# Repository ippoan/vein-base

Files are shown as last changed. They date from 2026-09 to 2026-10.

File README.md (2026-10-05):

# vein-base

M5Stack **Atom VoiceS3R** の下に積むベースです。**指静脈モジュール Waveshare Finger Vein Scanner Module (A)** を UART でつなぐための中継基板と、上蓋なしの 1 部品のケース(カップ)で構成しています。

ケース(`vein_base_v<版>_cup`)は床・ネジのボス・基板を支えるレールに、基板を囲む壁を立ち上げた形です。M5 の Atomic 系ベースと同じく、VoiceS3R は Ext.Pin のピンに刺して上に載せるだけで、外側は囲みません。壁の上端は VoiceS3R の底面から 0.25 mm 下で止め、ピンヘッダーのすき間を隠します(外形 24.4 × 33.1 × 9.25 mm、壁は全方向 1.4 mm 以上)。基板に合わせて USB-C と反対側(+y)へ伸びていて、その面に J3 のケーブル用の上へ開いた溝があります。

**3D プレビュー:** https://ippoan.github.io/vein-base/(回転・分解表示・部品の表示切替ができます)

3D プレビュー(GitHub Pages、main の CI が更新。各ページから型紙・加工図もダウンロードできます):

| 案 | ページ |
|---|---|
| vein-base(単体) | https://ippoan.github.io/vein-base/ |
| Vein Station(印刷筐体) | https://ippoan.github.io/vein-base/station/ |
| Vein Station SE(CoreS3 SE) | https://ippoan.github.io/vein-base/station-se/ |
| Vein Station PF(タカチ PF13-4-9) | https://ippoan.github.io/vein-base/station-pf/ |
| Vein Station SW(タカチ SW-85B) | https://ippoan.github.io/vein-base/station-sw/ |
| Vein Station SW75(タカチ SW-75B) | https://ippoan.github.io/vein-base/station-sw75/ |
| Vein Station SW130(タカチ SW-130B) | https://ippoan.github.io/vein-base/station-sw130/ |
| Vein Station 3D 印刷の試作 A(一列・薄型) | https://ippoan.github.io/vein-base/station-print-a/ |
| Vein Station 3D 印刷の試作 B(2 列・短い) | https://ippoan.github.io/vein-base/station-print-b/ |
| 指静脈 Unit(CS75N-B) | https://ippoan.github.io/vein-base/vein-unit-cs/ |
| 指静脈 Unit(SIC5-9-2B) | https://ippoan.github.io/vein-base/vein-unit-sic/ |

## 構成

```
VoiceS3R(Ext.Pin メス)
  └ 中継基板 20.0×29.9 mm(J1 1x5 / J2 1x4 オスピン、J3 MX1.25 4P 横型。全部品が表面 = VoiceS3R 側。J3 は VoiceS3R の外、USB-C の反対側の端)
  └ カップ 24.4×33.1(基板の下と周りだけ。VoiceS3R は囲まない。M2×12 ネジ 1 本で全体を VoiceS3R に共締め)
```

組み立て: VoiceS3R に基板を挿す → 指静脈のケーブルを J3 に挿す(挿さり具合を目で確かめられる)→ カップを下から差し込む(ケーブルは USB-C と反対側(+y)の壁の、上へ開いた溝を通る)→ 底から M2 ネジで締める。

- **挿し口:** 指静脈ケーブル(J3)は、VoiceS3R の USB-C / PORT.A(NFC 用)と**反対の面**に出ます。J3 は高さ 3.4 mm で VoiceS3R の下(すき間 2.54 mm)に入らないため、基板を VoiceS3R の外まで伸ばして載せています。
- **ケーブル:** 指静脈モジュール付属の 9P→4P ケーブルを使います。9P 側の端子を 1→5、2→6 の位置へ差し替えてください。
  付属ケーブルが使えない(端子の差し替えができない・長さが合わない)場合は、最悪 [eleshop.jp のハーネス製作](https://eleshop.jp/shop/e/eHARNESS/) で 4P(MX1.25)↔ 9P のケーブルを見積もります。

## 配線

| VoiceS3R Ext.Pin | 基板 | J3(4P) | モジュール 9P |
|---|---|---|---|
| G5(UART TX) | J1-2 | 1 | 5 RXD |
| G6(UART RX) | J1-3 | 2 | 6 TXD |
| 3V3 | J1-1 | 3 | 3 VCC |
| GND | J2-4 | 4 | 4 GND |

- UART は 57600 bps。
- NFC(M5Stack Unit NFC U216)は本体の PORT.A を使用(I2C:SDA=G2、SCL=G1)。

## ATOMIC Proto Kit 版(`vein_base_atomic`)

3D プリントのカップの代わりに、市販の M5Stack ATOMIC Proto Kit(A077)のケースに入れる版。基板の外形は M5 公式の ATOMIC-TYPE-A([M5_Hardware](https://github.com/m5stack/M5_Hardware) の `Common/Atomic_Type_A/Structures/Atomic_Type_A.dxf`、20 × 43.8 mm)をそのまま使い、中心の穴は φ4.2(メッキなし)。部品・配線表はカップ版と同じで、J3 は +y 端(ケース端面の開口側)に置く。両側の半円の切り欠き(ケースの柱よけ)のあいだは幅 8.6 mm しかないので、配線はそこを x −3.8〜+3.8 の中だけで通る。

- **発注対象は `fab/atomic/vein_base_atomic_v<版>_*`**(ガーバー zip・BOM・CPL)。カップ版の `vein_base_v<版>_*` と取り違えない。
- **JLCPCB では板厚 1.0 mm を選ぶ**(カップ版は 1.6 mm)。
- **J1 / J2 は差し込み側 4 mm の XFCN PZ254V-11-05P-A40(C42419912)/ -04P-A40(C42419911)**(v0.16〜)。v0.14 の ZHOURI(差し込み側 6 mm)は VoiceS3R が 1〜2 mm 浮いたため。
- 手で確かめる項目: J3 に挿したプラグがケース端面の開口 16 × 9.3 mm を通るか、ケースの柱 φ4.84 が基板の切り欠きに入るか。

## Vein Station(一体筐体・案)

VoiceS3R(vein-base の基板のみ。ケースは使わない)・指静脈モジュール・NFC ユニットを上向きに並べて収める卓上筐体の案。`station/build_station.py`(CadQuery)が筐体(ケース上部・底蓋)の STEP / STL と 3D プレビュー(https://ippoan.github.io/vein-base/station/)を作り、モジュール・プラグ・USB ケーブルとの干渉をチェックする。モジュールの外形は公式値(VoiceS3R・NFC は M5Stack 公式 STL の [Atom_VoiceS3R.stl](https://github.com/m5stack/M5_Hardware/blob/a240115c94b19ecf647f229c47fa9a8ce46ccdc4/Products/C126-ECHO_Atom_VoiceS3R/Structures/Atom_VoiceS3R.stl)・[Unit_NFC.stl](https://github.com/m5stack/M5_Hardware/blob/a240115c94b19ecf647f229c47fa9a8ce46ccdc4/Products/U216_Unit_NFC/Structures/Unit_NFC.stl)、指静脈は [Waveshare の製品ページ](https://www.waveshare.com/finger-vein-scanner-module-a.htm) の 59 × 26 × 15)。上面ボタン・ネジ頭などの細部とケーブルは写真からの実測。指静脈のコネクタ位置は未確定。基板は `pcb/station_board/`(r12)が生成する 60 × 35 mm の 1 枚基板で、VoiceS3R の Ext.Pin・指静脈 J3(G5/G6)・MAX3232(G7=送信 / G8=受信)・DIP(1+2 = Passthrough、3+4 = Cross)・DB9 オス RA をまとめ、接続口はすべて奥の壁に出す。同じ回路・同じ配線で外形を広げた版(`build_board.py pf` → `station_board_pf`、92 × 71)は、既製ケースタカチ PF13-4-9 用(印刷部品なし)。基板はケースに元からある基板用ボス(87 × 47)にタカチ TPS-M2.3-7 と M2.3 ねじで留め、モジュールは M3 オスメス六角スペーサーとナットで基板に立てる。60 × 35 の範囲と配線は共通。ケース側は `station/build_station_pf.py`(ケースはタカチ公式 STP の実測値からの簡略形状、STP は入れない)が、干渉チェック・3D プレビュー(`site/station-pf/`)・タカチの穴加工に出す DXF(天板の窓 2 つだけ)を作る。接続口はすべて背面なので背面パネルは付けない。基板の穴(H1..H8、B1..B4)はこのスクリプトと `build_board.py` の 2 か所にあるので一緒に直す。

### Vein Station ESP 基板(VoiceS3R の回路を基板に載せた版・案)

`pcb/station_esp_board/build_board.py`(e1)は、PF13-4-9 用の station 基板(92 × 71、穴・DB9・MAX3232・DIP・J3 の位置は同じ)に、Atom VoiceS3R を挿す代わりにその回路を直接載せた版。M5Stack 公開の回路図(`Sch_M5_AtomS3R_v0.4.1` / `Sch_M5_AtomEchoS3R_Audio_v1.0`)と同じ GPIO でつなぐので、VoiceS3R 用のファームがそのまま使える見込み。

- ESP32-S3-WROOM-1-N8R8(技適付きモジュール。VoiceS3R の PICO-1 と同じ Flash 8 MB / PSRAM 8 MB)。アンテナは背面(−y)の端から 1.25 mm はみ出す。
- USB-C(G19 / G20 を直結)、AMS1117-3.3、EN / BOOT ボタン。
- ES8311(I2C: SDA G45 / SCL G0、I2S: MCLK G11 / BCLK G17 / WS G3 / G48 → DSDIN / ASDOUT → G4)、MEMS マイク(LinkMems LMA3729T381。VoiceS3R のマイクは在庫切れ)、NS4150B(CTRL G18)、13 × 13 mm の SMD スピーカー。スピーカーとマイクは、PF の天板にある旧 VoiceS3R 用の窓の下に置く。
- Grove 2 口: J6 = Unit NFC(G2 SDA / G1 SCL、VoiceS3R の PORT.A と同じ)、J7 = 予備(G38 / G39)。IR LED は載せない(G47 は空き)。
- **初回だけ**: G45(SDA のプルアップ付き)は Flash 電圧のストラップなので、最初に BOOT を押したまま EN を押し、`espefuse.py --port <ポート> set_flash_voltage 3.3V` で Flash 電圧を eFuse に書く。M5Unified は PICO-1 のパッケージで VoiceS3R を見分けるので、`cfg.fallback_board = m5::board_t::board_M5AtomVoiceS3R` を指定する。
- 外形は 2 種類(回路は同じ): PF13-4-9 用 92 × 71(`build_board.py`、`fab/station_esp/`。筐体側 `station/build_station_pf.py` はまだ VoiceS3R 版のまま)と、SW-85B 用 52 × 76(`build_board.py sw`、`fab/station_esp_sw/`)。
- 配線は freerouting 2.4.1 の結果を `station_esp_board[_sw].ses` に入れてある(`build_board.py [sw] dsn` で DSN を出して再配線)。CI で gerber / CPL / DRC。

### Vein Station SW(タカチ SW-85B・別案)

ケースを小さくする案。VoiceS3R が無くなった分、中身は指静脈・NFC・DB9 と ESP 基板だけなので、タカチで一番小さく収まる SW-85B(60 × 40 × 85、はめ込み式、¥350。PF13-4-9 の半分以下の面積)に入れる。`station/build_station_sw.py` がケースの簡略形状(タカチの外形図から)と干渉チェック、3D プレビュー(`site/station-sw/`)を作る。

- 基板(52 × 76)は床に貼るタカチ ASL-12 × 3 に差し込む(床のリブの間)。指静脈は M3 × 12 の上に立てて、カバーの窓から 3.8 出す。NFC は M3 × 10 の上で、カバーの裏に貼る(窓なし)。
- 加工はカバーの窓(指静脈)とスピーカー・マイクの穴、端面の DB9 のフードが入る角穴・USB-C プラグの穴・J7 ケーブルの穴。
- 幅の余裕は小さい(指静脈 26 + NFC 24 に対して内寸 52.8)。発注前に指静脈の実物を測る。床のリブの高さは図面に無いので 2.0 と仮定。

### Vein Station SW75(タカチ SW-75B・NFC を外に出す最小案)

NFC Unit を箱の外に置き(Grove ケーブルで J6 へ)、SW-75B(50 × 30 × 75、¥200。PF13-4-9 の約 1/3 の面積で高さも 10 低い)に指静脈・DB9 と ESP 基板だけを収める。`station/build_station_sw75.py` が干渉チェックと 3D プレビュー(`site/station-sw75/`)、基板は `build_board.py sw75`(40.8 × 68.1、`fab/station_esp_sw75/`、BOM は `jlc_bom_sw75.csv`)。

- 片面実装のまま収めるため、抵抗・コンデンサは 0402、LDO は SOT-89、ボタンは Alps SKRPACE010(4.2 × 3.2)、線幅 / 間隔は 5 / 5 mil。
- DIP スイッチの代わりに 0 Ω(R11 / R12 = ストレート、実装済み)とはんだジャンパー(JP1 / JP2 = クロス)。クロスにするときは R11 / R12 を外して JP1 / JP2 をはんだでつなぐ。
- DB9 と USB-C は +x の側面、Grove 2 口は +y の端面から出す。WROOM のアンテナは -x の壁側。
- 基板は指静脈の M3 × 6 スペーサーにぶら下げる形で、うち 2 本(H1 / H4)のオス側を床に貼るタカチ ASR-7 にねじ込む。指静脈はカバーから 2.8 出す。
- 指静脈のケーブル: モジュールの -y 端のソケットから出て、基板の -y 端の切り欠き(6 × 2.5)から基板の下へ逃がし、余りは基板の下(床まで 7.2)に収める。同じ切り欠きから J3(口は同じ -y 向き)へ入る。

### Vein Station SW130(タカチ SW-130B・全部入りの細い案)

タカチ SW-130B(40 × 25 × 130、¥360)に、−y から DB9 → DIP と指静脈のケーブル → 指静脈 → VoiceS3R を一列に全部入れる。`station/build_station_sw130.py` が干渉チェック・3D プレビュー(https://ippoan.github.io/vein-base/station-sw130/)・加工図(DXF / PDF)と A4 原寸の型紙、タカチへの見積もり依頼に付ける加工位置図(A4 横 1 枚・日本語、`vein_station_<REV>_positions.pdf`)を作る。基板は `build_board.py sw130`(34.8 × 122.7、片面、`fab/station_sw130/`、BOM は `jlc_bom_sw130.csv`)。詳細は `CLAUDE.md` の SW130 案の節。

### Vein Station SE(CoreS3 SE 版・案)

本体を CoreS3 SE に替え、RS232M Module 13.2(アルコールチェッカー FC-1200 用)・NFC・指静脈を収める版。LAN は使わず、USB 1 本で Windows PC につなぐ。`station/build_station_se.py` が筐体と 3D プレビュー(https://ippoan.github.io/vein-base/station-se/)を作る。CoreS3 SE には PORT.B のコネクタが無いので、指静脈の UART(G8/G9)は RS232M の下に挿す M-Bus 分岐基板から取り出す。CoreS3 SE と Unit NFC は M5Stack 公式 STL([m5stack/M5_Hardware](https://github.com/m5stack/M5_Hardware)、MIT)を commit 固定で取得して表示とポート位置に使う(`station/cad/`、git 管理外)。CoreS3 SE の PWR・USB-C・PORT.A はすべて左側面にある。指静脈モジュールの外形は公式値(コネクタ位置は未確定)。RS232M・分岐基板は仮の箱。計画は #14。

## フォルダ構成

| パス | 内容 |
|---|---|
| `pcb/` | KiCad 7 の基板データと生成スクリプト(`build_pcb.py`、KiCad 付属の Python で実行) |
| `VERSION` | 版番号。出力ファイル名(`vein_base_v<版>_*`)と基板裏のシルクに入る |
| `case/` | ケース生成スクリプト(`build_case.py`、CadQuery) |
| `pcb/jlc_bom.csv` | JLCPCB 用 BOM の元データ(LCSC 品番) |
| `pcb/station_board/jlc_bom.csv` | station 基板の JLCPCB 用 BOM の元データ |
| `pcb/station_esp_board/jlc_bom.csv` | station ESP 基板(VoiceS3R の回路を載せた版、PF 用・SW 用で共通)の JLCPCB 用 BOM の元データ |
| `pcb/station_esp_board/jlc_bom_sw75.csv` | 同じく SW-75B 用(0402 部品)の BOM |
| `fab/` | CI の出力先(git 管理外)。JLCPCB 発注用(ガーバー zip、BOM、CPL)、原寸の確認用 PDF、基板の STEP |
| `tools/` | CI 用スクリプト(DRC チェック、JLC 用 CPL 変換、3D プレビュー生成と干渉チェック) |

## CI(GitHub Actions)

`main` への push で `.github/workflows/build.yml` が次を順に実行します。

1. KiCad 7 で基板を生成する。ガーバー、ドリル、CPL、原寸 PDF、STEP を出力する。
2. DRC をかけ、違反があれば失敗させる。
3. CadQuery でケースを生成する。
4. 3D プレビューを生成し、ケースと部品・VoiceS3R の干渉チェックを行う(干渉があれば失敗)。
5. 製造データを Artifacts(`vein-base-v<版>-fab`)にアップロードする。ファイル名はすべて `vein_base_v<版>_*` で、発注時に版を取り違えないようにしている。STL / STEP / PDF 等の生成物はリポジトリに置かず、常に Artifacts から取る。
6. 3D プレビューを GitHub Pages に公開する。

寸法や配線を変えるときは、`pcb/build_pcb.py` / `case/build_case.py` を編集して push すれば、製造データと 3D プレビューがまとめて更新されます。

## 設計根拠と検証

- **ピンヘッダー位置とネジ穴:** M5Stack 公式 [M5_Hardware](https://github.com/m5stack/M5_Hardware) の `Common/Atomic_Type_A` による。
- **ピン割り当て:** VoiceS3R 本体底面のシルク印刷による。
- **KiCad DRC:** 未接続 0、クリアランス違反なし。
- **干渉チェック:** 基板、部品、ケーブル、ネジ、VoiceS3R の外形との干渉は体積 0(問題なし)。
- **station 基板の RS232(実機テスト済み、2026-10-01):** 届いた station 基板 r10 に VoiceS3R を挿し、[alc-app-s3](https://github.com/ippoan/alc-app-s3) の `atoms3-timecard` の `station` 版(`0.1.0+74579fe`、Pages の `firmware/alc-hub-atoms3-timecard-station-merged.bin` を `espflash write-bin 0x0` で書き込み)で確認。SW1 は 1+2 ON(Passthrough)。DB9 に FC-1200B をつなぎ、G7 = 送信 / G8 = 受信(MAX3232、9600 8N1)で接続応答 → 暖機 → 吹き込み待ち → 測定 → 測定値(0.000 mg/L)まで USB コンソールに出た。未確認: 指静脈(J3、G5/G6。`vein` 版のファームが要る)、NFC、SW1 の Cross(3+4 ON)。

## 発注前の確認(未検証の項目)

1. `vein_base_v<版>_fitcheck_1to1_seen_from_below.pdf` を原寸(100%)で印刷し、VoiceS3R の底面に当てる。ピン列の左右とネジ穴の位置が合うか確認する。
2. 付属ケーブルの結線がストレート(4P の n 番 = 9P の n 番)か、テスターで確認する。
3. 実装は JLCPCB の Economic PCBA(片面、Top)で全部品を付ける。J3 は LCSC C696092(Molex 53261-0471)。JLC の実装プレビューで、J1/J2/J3 がすべて表面に載り、J3 の開口が基板の +y 端(USB-C と反対)を向いているか確認する。
4. M2 ネジの長さ、VoiceS3R のメスヘッダーの深さ、VoiceS3R 底面の出っ張りの有無を実物で確認する。
5. ケースの素材は DMM.make の「PA12｜MJF」(グレー、磨きなし)。形の確認だけならエコノミーレジン(SLA)でよい。

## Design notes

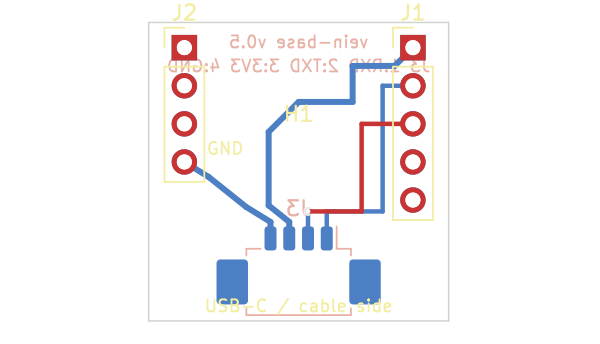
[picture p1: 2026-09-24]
pcb/pcb_top_view.png

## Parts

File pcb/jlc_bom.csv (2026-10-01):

Comment | Designator | Footprint | LCSC Part # | Note
Pin header 1x5 2.54mm male, straight (XFCN PZ254V-11-05P-A40) | J1 | PinHeader_1x05_P2.54mm_Vertical | C42419912 | THT; mating 4mm / tail 3mm / plastic 2.5mm
Pin header 1x4 2.54mm male, straight (XFCN PZ254V-11-04P-A40) | J2 | PinHeader_1x04_P2.54mm_Vertical | C42419911 | THT; mating 4mm / tail 3mm / plastic 2.5mm
Molex PicoBlade 53261-0471 (MX1.25 4P RA SMD) | J3 | Molex_PicoBlade_53261-0471_1x04-1MP_P1.25mm_Horizontal | C696092 | SMD top side (same side as J1/J2); opening faces the +y edge (away from USB-C)

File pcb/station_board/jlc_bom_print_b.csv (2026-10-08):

Comment | Designator | Footprint | LCSC Part # | Note
Pin header 1x5 2.54mm male, straight (XFCN PZ254V-11-05P-A40) | J1 | PinHeader_1x05_P2.54mm_Vertical | C42419912 | THT; mating 4mm / tail 3mm / plastic 2.5mm (same as vein-base)
Pin header 1x4 2.54mm male, straight (XFCN PZ254V-11-04P-A40) | J2 | PinHeader_1x04_P2.54mm_Vertical | C42419911 | THT; mating 4mm / tail 3mm / plastic 2.5mm (same as vein-base)
Molex PicoBlade 53398-0471 (MX1.25 4P vertical SMD) | J3 | Molex_PicoBlade_53398-0471_1x04-1MP_P1.25mm_Vertical | C17617036 | Top side; just in front of the vein module's 9P plug, locking window (tails) to the -y edge; pads -x to +x = 3V3 / GND / G5 (RXD) / G6 (TXD)
MAX3232EIDR (TI, RS232 transceiver 3-5.5V) | U1 | SOIC-16_3.9x9.9mm_P1.27mm | C193666 | powered from 3V3
100nF 50V X7R 0603 | C1,C2,C3,C4,C5 | C_0603_1608Metric | C14663 | Basic part
KINGTEK DSHP04TSGET (DIP switch 4P SPST, SMD, half pitch 1.27mm, 2.30mm high) | SW1 | SW_DIP_SPSTx04_Slide_KingTek_DSHP04TS_W7.62mm_P1.27mm | C40736 | under the VoiceS3R (3.2 high at most there); set 1+2 ON (passthrough) after assembly, with the VoiceS3R off
DB9 male right angle, 4-40 screw lock (Ckmtw D-DMR009PM-D002) | J4 | DSUB-9_Male_Horizontal_P2.77x2.84mm_EdgePinOffset7.70mm_Housed_MountingHolesOffset9.12mm | C141880 | THT; flange on the -y board edge (the -y end wall)
JST PH 4P right angle SMD (takes the Grove plug), S4B-PH-SM4-TB(LF)(SN) | J6 | JST_PH_S4B-PH-SM4-TB_1x04-1MP_P2.00mm_Horizontal | C265102 | Unit NFC: 1 = G38 (SDA) / 2 = G39 (SCL) / 5V / GND; opening on the +x edge (the reset's side | just short of the VoiceS3R); the genuine JST part of the footprint (JLC found the HY2.0 C722729's pins off the pads); its front stands 2.3 inside the edge
4.7k 1% 0603 | R1,R2 | R_0603_1608Metric | C23162 | Basic part; I2C pull-ups for J6 (G38 / G39 to 3V3)

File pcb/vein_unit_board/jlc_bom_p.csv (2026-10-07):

Comment | Designator | Footprint | LCSC Part # | Note
Molex PicoBlade 53398-0471 (MX1.25 4P vertical SMD) | J1 | Molex_PicoBlade_53398-0471_1x04-1MP_P1.25mm_Vertical | C17617036 | Top side; beside the module's +y side; 1 = 3V3 / 2 = GND / 3 = RXD / 4 = TXD (the 9P's 3..6 in order); JLC's footprint = KiCad's (pin 1 at -x of the footprint) with its origin 0.125 lower
JST PH 4P right angle SMD (takes the Grove plug), S4B-PH-SM4-TB(LF)(SN) | J2 | JST_PH_S4B-PH-SM4-TB_1x04-1MP_P2.00mm_Horizontal | C265102 | Top side; opening faces the +x edge; the genuine JST part of the footprint (JLC found the HY2.0 C722729's pins off the pads on the station board); rotation 180 in the CPL as the station board (#96)
XC6206P332MR-G (3.3 V LDO 200 mA SOT-23) | U1 | SOT-23 | C5446 | Basic part
1uF 50V X5R 0603 (Samsung CL10A105KB8NNNC) | C1,C2 | C_0603_1608Metric | C15849 | Basic part; C1 = 5 V in / C2 = 3.3 V out

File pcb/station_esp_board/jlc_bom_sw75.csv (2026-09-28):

Comment | Designator | Footprint | LCSC Part # | Note
ESP32-S3-WROOM-1-N8R8 (8 MB flash / 8 MB octal PSRAM) | U2 | ESP32-S3-WROOM-1 | C2913201 | antenna to the -x edge (flush); burn the flash voltage eFuse (3.3 V) before the first boot (GPIO45 is pulled up)
USB-C 16P receptacle (Korean Hroparts TYPE-C-31-M-12) | J5 | USB_C_Receptacle_HRO_TYPE-C-31-M-12 | C165948 | opening on the +x edge
AMS1117-3.3 (SOT-89) | U3 | SOT-89-3 | C880752 | 800 mA
ES8311 audio codec (QFN-20 3x3) | U4 | QFN-20-1EP_3x3mm_P0.4mm_EP1.65x1.65mm | C962342 | I2C 0x18
NS4150B class-D amplifier (MSOP-8) | U5 | MSOP-8_3x3mm_P0.65mm | C189961
LinkMems LMA3729T381-OAC03 analog MEMS mic (top port) | MK1 | MEMS_Mic_LinkMems_LMA3729T381_3.76x2.95mm | C41347996 | pin 1 corner as JLC's footprint; check it in the assembly preview
GSPK1304S-8R0.5W SMD speaker 13x13x4, 8 ohm | SP1 | Speaker_SMD_GSPK1304S_13x13mm | C2847318 | sound opening up
HY2.0-4P right angle SMD (Grove), JST PH S4B-PH-SM4-TB footprint | J6,J7 | JST_PH_S4B-PH-SM4-TB_1x04-1MP_P2.00mm_Horizontal | C722729 | J6 = Unit NFC (G2 SDA / G1 SCL) / J7 = spare (G38 / G39); openings on the +y edge; check the pads against JLC's footprint in the assembly preview
Tact switch 4.2x3.2 (Alps SKRPACE010) | SW2 | SW_Push_Alps_SKRPACE010 | C139797 | EN (reset); two diagonal pads used
Side-push tact switch 3.5x2.9 (Panasonic EVQP7C01P) | SW3 | SW_SPST_EVQP7C | C388883 | BOOT (G0); plunger over the +x edge (pressed through a pin hole in the case side); check it faces +x in the assembly preview
Ferrite bead 120R@100MHz 0402 (Murata BLM15AG121SN1D) | FB1 | L_0402_1005Metric | C85812 | mic supply
Molex PicoBlade 53261-0471 (MX1.25 4P RA SMD) | J3 | Molex_PicoBlade_53261-0471_1x04-1MP_P1.25mm_Horizontal | C696092 | opening faces +y (the vein cable)
MAX3232EIDR (TI, RS232 transceiver 3-5.5V) | U1 | SOIC-16_3.9x9.9mm_P1.27mm | C193666 | powered from 3V3
DB9 male right angle, 4-40 screw lock (Ckmtw D-DMR009PM-D002) | J4 | DSUB-9_Male_Horizontal_P2.77x2.84mm_EdgePinOffset7.70mm_Housed_MountingHolesOffset9.12mm | C141880 | THT; flange on the +x board edge
0R 0402 (straight link, DB9 2/3 as a PC) | R11,R12 | R_0402_1005Metric | C17168 | Basic part; for cross take them off and bridge JP1 / JP2 (solder jumpers)
100nF 16V X7R 0402 | C1,C2,C3,C4,C5,C8,C10,C13,C20,C22,C23,C25 | C_0402_1005Metric | C1525 | Basic part
1uF 25V X5R 0402 | C11,C14,C15,C16,C17,C18,C19,C21,C24 | C_0402_1005Metric | C52923 | Basic part
10uF 6.3V X5R 0402 | C6,C9,C12,C26 | C_0402_1005Metric | C15525 | Basic part
22uF 6.3V X5R 0603 | C7 | C_0603_1608Metric | C59461 | Basic part; AMS1117 output
5.1k 1% 0402 | R1,R2 | R_0402_1005Metric | C25905 | Basic part; USB-C CC1 / CC2
22R 1% 0402 | R3,R4 | R_0402_1005Metric | C25092 | Basic part; USB D- / D+
10k 1% 0402 | R5,R10 | R_0402_1005Metric | C25744 | Basic part; EN pull-up / NS4150B CTRL pull-down
4.7k 1% 0402 | R6,R7 | R_0402_1005Metric | C25900 | Basic part; I2C SCL (G0) / SDA (G45) pull-ups
150k 1% 0402 | R8,R9 | R_0402_1005Metric | C25755 | NS4150B inputs

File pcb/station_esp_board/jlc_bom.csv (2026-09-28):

Comment | Designator | Footprint | LCSC Part # | Note
ESP32-S3-WROOM-1-N8R8 (8 MB flash / 8 MB octal PSRAM) | U2 | ESP32-S3-WROOM-1 | C2913201 | antenna end 1.25 over the -y edge; burn the flash voltage eFuse (3.3 V) before the first boot (GPIO45 is pulled up)
USB-C 16P receptacle (Korean Hroparts TYPE-C-31-M-12) | J5 | USB_C_Receptacle_HRO_TYPE-C-31-M-12 | C165948 | opening on the -y edge
AMS1117-3.3 (SOT-223) | U3 | SOT-223-3_TabPin2 | C6186 | Basic part
ES8311 audio codec (QFN-20 3x3) | U4 | QFN-20-1EP_3x3mm_P0.4mm_EP1.65x1.65mm | C962342 | I2C 0x18
NS4150B class-D amplifier (MSOP-8) | U5 | MSOP-8_3x3mm_P0.65mm | C189961
LinkMems LMA3729T381-OAC03 analog MEMS mic (top port) | MK1 | MEMS_Mic_LinkMems_LMA3729T381_3.76x2.95mm | C41347996 | pin 1 corner as JLC's footprint; check it in the assembly preview
GSPK1304S-8R0.5W SMD speaker 13x13x4, 8 ohm | SP1 | Speaker_SMD_GSPK1304S_13x13mm | C2847318 | sound opening up
HY2.0-4P right angle SMD (Grove), JST PH S4B-PH-SM4-TB footprint | J6,J7 | JST_PH_S4B-PH-SM4-TB_1x04-1MP_P2.00mm_Horizontal | C722729 | J6 = Unit NFC (G2 SDA / G1 SCL) | J7 = spare (G38 / G39); openings face +y; check the pads against JLC's footprint in the assembly preview
Tact switch 5.1x5.1 (XKB TS-1187A-B-A-B) | SW2,SW3 | SW_Push_1P1T_XKB_TS-1187A | C318884 | Basic part; SW2 = EN (reset) / SW3 = BOOT (G0)
Ferrite bead 100R@100MHz 0805 (GZ2012D101TF) | FB1 | L_0805_2012Metric | C1015 | Basic part; mic supply
Molex PicoBlade 53261-0471 (MX1.25 4P RA SMD) | J3 | Molex_PicoBlade_53261-0471_1x04-1MP_P1.25mm_Horizontal | C696092 | Top side; opening faces the +y edge (vein module)
MAX3232EIDR (TI, RS232 transceiver 3-5.5V) | U1 | SOIC-16_3.9x9.9mm_P1.27mm | C193666 | powered from 3V3
CTS 219-4LPSTRF (DIP switch 4P SPST, SMD gull wing, low profile) | SW1 | SW_DIP_SPSTx04_Slide_6.7x11.72mm_W8.61mm_P2.54mm_LowProfile | C3034155 | set 1+2 ON (passthrough) after assembly
DB9 male right angle, 4-40 screw lock (Ckmtw D-DMR009PM-D002) | J4 | DSUB-9_Male_Horizontal_P2.77x2.84mm_EdgePinOffset7.70mm_Housed_MountingHolesOffset9.12mm | C141880 | THT; flange on the -y board edge
100nF 50V X7R 0603 | C1,C2,C3,C4,C5,C8,C10,C13,C20,C22,C23,C25 | C_0603_1608Metric | C14663 | Basic part
1uF 50V X5R 0603 | C11,C14,C15,C16,C17,C18,C19,C21,C24 | C_0603_1608Metric | C15849 | Basic part
10uF 25V X5R 0805 | C6,C9,C12,C26 | C_0805_2012Metric | C15850 | Basic part
22uF 25V X5R 0805 | C7 | C_0805_2012Metric | C45783 | Basic part; AMS1117 output
5.1k 1% 0603 | R1,R2 | R_0603_1608Metric | C23186 | Basic part; USB-C CC1 / CC2
22R 1% 0603 | R3,R4 | R_0603_1608Metric | C23345 | Basic part; USB D- / D+
10k 1% 0603 | R5,R10 | R_0603_1608Metric | C25804 | Basic part; EN pull-up / NS4150B CTRL pull-down
4.7k 1% 0603 | R6,R7 | R_0603_1608Metric | C23162 | Basic part; I2C SCL (G0) / SDA (G45) pull-ups
150k 1% 0603 | R8,R9 | R_0603_1608Metric | C22807 | Basic part; NS4150B inputs

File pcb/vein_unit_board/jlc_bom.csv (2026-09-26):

Comment | Designator | Footprint | LCSC Part # | Note
Molex PicoBlade 53261-0471 (MX1.25 4P RA SMD) | J1 | Molex_PicoBlade_53261-0471_1x04-1MP_P1.25mm_Horizontal_NarrowMP | C696092 | Top side; opening faces -x (the vein module's plug); MP pads narrowed in pcb/vein_base.pretty
HY2.0-4P right angle SMD (Grove), JST PH S4B-PH-SM4-TB footprint | J2 | JST_PH_S4B-PH-SM4-TB_1x04-1MP_P2.00mm_Horizontal | C722729 | Top side; opening faces the +x edge; check the pads against JLC's footprint in the assembly preview
XC6206P332MR-G (3.3 V LDO 200 mA SOT-23) | U1 | SOT-23 | C5446 | Basic part
1uF 50V X5R 0603 (Samsung CL10A105KB8NNNC) | C1,C2 | C_0603_1608Metric | C15849 | Basic part; C1 = 5 V in / C2 = 3.3 V out

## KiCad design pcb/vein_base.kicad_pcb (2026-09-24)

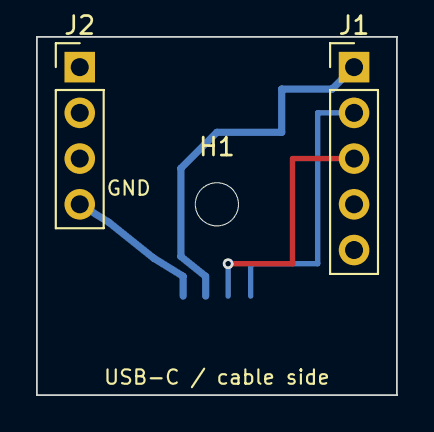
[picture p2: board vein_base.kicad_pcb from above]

Board: 2 copper layers, 20.0 x 19.9 mm, 4 parts (1 on the bottom side), 4 nets.

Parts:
H1: MountingHole_2.2mm_M2
J1: Hdr 1x5 2.54 (3V3,G5,G6,G7,G8); PinHeader_1x05_P2.54mm_Vertical
J2: Hdr 1x4 2.54 (G39,G38,5V,GND); PinHeader_1x04_P2.54mm_Vertical
J3: MX1.25-4P RA SMD (Molex 53261-0471); Molex_PicoBlade_53261-0471_1x04-1MP_P1.25mm_Horizontal

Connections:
3V3: J1.1, J3.3
G5_TX: J1.2, J3.1
G6_RX: J1.3, J3.2
GND: J2.4, J3.4

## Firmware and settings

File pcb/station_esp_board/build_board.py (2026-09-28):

"""Vein Station ESP board (e1): the station board with the Atom VoiceS3R's circuit on the board itself instead of the
Atom on the Ext.Pin, in two outlines of the same circuit:
  (default)  92 × 71 for the Takachi PF13-4-9 (the pf outline of pcb/station_board, same holes / DB9 / MAX3232 / DIP / J3)
  'sw'       52 × 76 for the Takachi SW-85B (station/build_station_sw.py): every part placed anew (POS), the vein module
             and the Unit NFC on M3 spacers from the board, the board on three Takachi ASL-12 stuck to the floor
  'sw75'     40.8 × 68.1 for the Takachi SW-75B (station/build_station_sw75.py), the Unit NFC outside on its cable:
             DB9 / USB-C on the +x side, both Groves on the +y end, 0402 passives, SOT-89 LDO, EN on a SKRPACE010 inside
             and BOOT on a side-push Panasonic EVQP7C on the +x edge between the DB9 and the USB-C (pressed with a pin
             through a hole in the case's side, so a built station can be put into download mode), the
             straight / cross DIP as 0R links (R11 / R12) + open solder jumpers (JP1 / JP2), 5 / 5 mil tracks; the board
             hangs on the vein module's spacers (two of them into Takachi ASR-7 stuck to the floor). Its own BOM
             (jlc_bom_sw75.csv)
The circuit follows M5Stack's schematics (Sch_M5_AtomS3R_v0.4.1 / Sch_M5_AtomEchoS3R_Audio_v1.0_20250716) with the
same GPIOs, so VoiceS3R firmware keeps working:
  - U2 ESP32-S3-WROOM-1-N8R8 (the VoiceS3R's ESP32-S3-PICO-1 has the same 8 MB flash + 8 MB octal PSRAM; the
        module brings its own antenna and radio certification). Antenna out over the -y edge (the open back), 1.0
        past it, its keep-out (the footprint's rule area) clear of copper.
  - J5 USB-C (native USB, G19 = D-, G20 = D+ through 22 Ω, CC1/CC2 5.1 k), U3 AMS1117-3.3 (5 V -> 3.3 V),
        SW2 = EN (reset, 10 k / 1 µF), SW3 = BOOT (G0 to GND)
  - U4 ES8311 codec on I2C (SDA G45, SCL G0, 4.7 k pull-ups, CE low = 0x18) and I2S (MCLK G11, BCLK G17, WS G3,
        G48 -> DSDIN, ASDOUT -> G4), MK1 analog MEMS mic (LinkMems LMA3729T381, top port; the VoiceS3R's
        MSM381A3729H9BPC is out of stock) into MIC1P, MIC1N to GND through 1 µF, mic supply through FB1
  - U5 NS4150B class-D amp on 3V3 (as the VoiceS3R), CTRL = G18 (10 k pull-down), inputs from OUTP / OUTN through
        100 nF + 150 k, SP1 13 × 13 SMD speaker (GSPK1304S 8 Ω 0.5 W) on the board
  - J6 Grove (HY2.0 4P RA) for the Unit NFC: 1 = G2 (SDA), 2 = G1 (SCL), 3 = 5V, 4 = GND (the VoiceS3R's PORT.A);
        J7 Grove beside it, spare: 1 = G38, 2 = G39, 3 = 5V, 4 = GND (the two GPIOs the VoiceS3R's Ext.Pin had)
  - no IR LED (G47 unused), no user button (G41 unused)
  - the rest as station_board r12 pf, in the same places: J3 vein (G5 -> RXD, G6 <- TXD), U1 MAX3232 (G7 -> T1IN,
        R1OUT -> G8), SW1 DIP (1+2 pass / 3+4 cross), J4 DB9 male RA on the -y edge, H1..H8 M3 module spacers,
        B1..B4 M2.3 over the case's PCB bosses
GPIO45 is the VDD_SPI strap and the SDA pull-up holds it high at reset: burn the flash voltage eFuse once before the
first boot (hold BOOT, tap EN or plug the USB in, then `espefuse.py --port <port> set_flash_voltage 3.3V`), as the
WROOM-1's flash is 3.3 V.
M5Unified detects the VoiceS3R by the PICO-1 package, so set cfg.fallback_board = board_M5AtomVoiceS3R (or configure
the codec yourself).

Board coords are the station board's (origin = where the VoiceS3R stood, +y = away from the back edge, F up).
The speaker and the mic sit under the PF case's old VoiceS3R window (|x|, |y| <= 10.8 in these coords).
In 'sw' the coords are the SW-85B case's instead (origin = case centre, the DB9 / USB-C end = -y); the speaker and
the mic sit in front of the NFC under holes in the cover, the WROOM's antenna on the front edge.
Routing comes from freerouting and is kept in station_esp_board[_sw|_sw75].ses (the board file itself is always generated):
    python3 build_board.py [sw|sw75] dsn   # placement only -> .dsn (freerouting 2.4.1 -> .ses)
    python3 build_board.py [sw|sw75]       # placement + tracks/vias from the .ses -> station_esp_board[_sw|_sw75].kicad_pcb
Run with KiCad's python from pcb/station_esp_board/.
The sw75 .ses since the BOOT button moved to the +x edge keeps the earlier routing and has only the nets around the
moved USB-C / BOOT (5V, CC1 / CC2, UDP / UDN, G0 and the GND near J5) routed again by freerouting (a full reroute left
G4 unrouted), merged into one file.
"""
import math, os, re, sys
import pcbnew

HERE = os.path.dirname(os.path.abspath(__file__))
sys.path.insert(0, os.path.join(HERE, '..'))
from kicad_ses import import_ses  # noqa: E402

SW75 = 'sw75' in sys.argv[1:]
SW = 'sw' in sys.argv[1:]
REV = 'e1'
NAME = 'station_esp_board' + ('_sw75' if SW75 else '_sw' if SW else '')
FP = '/usr/share/kicad/footprints/'
LOCAL = os.path.join(HERE, '..') + '/'         # pcb/vein_base.pretty (the project's own footprints)
OX, OY = 100.0, 100.0
mm = pcbnew.FromMM
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

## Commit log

2026-09-24 vein-base v0.5: PCB, case, CI 3D preview
    [jlc_bom.csv, vein_base.kicad_pcb, vein_base_pcb.step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]
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2026-09-24 Put the version in every output file name (#5)
    Add VERSION (0.6) as the single source for the version. Output files are
    now vein_base_v<ver>_* (gerbers zip, BOM, CPL, fit-check PDFs, PCB/case
    STEP and STL) and the artifact is vein-base-v<ver>-fab, so files for
    different revisions cannot be mixed up when ordering.
    Generated outputs are no longer tracked in git (they went stale and the
    v0.5 STL was nearly ordered). The BOM source moves to pcb/jlc_bom.csv
    with the LCSC part numbers.
    [jlc_bom.csv, vein_base_pcb.step, vein_base_plate.step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]
2026-09-24 Add Vein Station enclosure draft with 3D preview (r4) (#7)
    station/build_station.py models the desktop enclosure that holds the
    VoiceS3R (+ vein-base), the finger vein module and Unit NFC facing up
    (NFC vertical on the left, ports and cable bay on the right, USB exit
    through the right wall). It exports the shell and lid as STEP/STL,
    checks them against the modules, plugs and USB cable, and writes the
    3D preview to site/station/.
    Also fix the vein-base preview: PORT.A sits at the VoiceS3R bottom
    face with USB-C above it (the reference boxes were swapped).
2026-09-24 Vein Station r5: show the VoiceS3R top and hold modules with frames (#8)
    The VoiceS3R was only kept by a 1 mm lip with 0.5 mm play and could
    slide into the cable bay. Now its top is flush and fully visible, each
    module is located sideways by a 1.2 mm frame hanging from the top plate
    (0.2 mm clearance, open where plugs come out), and VoiceS3R + vein-base
    sit on a pad on the lid, held by one M2x16 screw into the vein-base.
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2026-09-24 Vein Station r8: halve the height of the locating frames (#11)
    Short frames are less likely to snap off. Each frame now hangs half as
    far from the top plate: NFC 3.75, vein 4.25, VoiceS3R 5.25 (corner posts
    on its port side 2.25).
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2026-09-24 ci: concurrency をブランチごとにし、PR の push が main の build を打ち切らないようにする (#26)
    group が pages 固定だったため、PR への push が main の build と Pages デプロイまで
    cancel-in-progress で打ち切りうる状態だった。PR #25 では 1 回目の commit の build が
    2 回目の push で打ち切られ、auto-merge が failure を出した。
    - workflow: group を build-<ref> にし、打ち切りは PR のときだけ (main は全 run を完走)
    - deploy job: group pages / cancel-in-progress false で、Pages のデプロイは 1 本ずつ順番に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
2026-09-25 feat(station): station 基板の部品を LCSC で選び、BOM と CPL の補正を足す (#30)
    * Vein Station 基板の JLC BOM を追加 (全部品に LCSC 品番)
    U1 MAX3232EIDR C193666 / SW1 CTS 219-4LPSTRF C3034155 / J4 DB9M RA C141880 /
    C1-C5 C14663 (Basic) / J1 C5156614 / J2 C5116483 / J3 PicoBlade C696092。
    footprint はすべて build_board.py の現行のままで合うため、配線 (.ses) は変更なし。
    Refs ippoan/vein-base#17
    * station 基板の CPL を JLC の footprint の向きと原点に合わせる
    make_jlc_cpl.py に --corrections を足す (省略時の出力は今と同じ)。
    pcb/station_board/jlc_cpl_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
    [jlc_bom.csv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]
2026-09-25 fix(pcb): vein_base 基板の J3 を在庫品に替え、CPL に JLC 向けの補正 (裏面対応) を足す (#31)
    * fix(pcb): vein_base 基板の J3 を在庫のある C696092 にし、CPL に JLC 向けの補正を足す
    - pcb/jlc_bom.csv: J3 の LCSC を C240847 (Not available) → C696092 (同じ Molex 53261-0471、station で採用済み)
    - tools/make_jlc_cpl.py: Bottom 面の補正に対応。座標はミラーしない (EasyEDA 公式)、
    オフセットは KiCad の裏返し (footprint y のミラー) を反映、回転は下から見て CCW = (180 - Rot + 補正)
    - pcb/jlc_cpl_corrections.csv: vein_base 用の補正表 (J1/J2/J3、値は station と同じ)
    - build.yml: vein_base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
    [jlc_bom.csv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]
2026-09-25 fix(pcb): vein_base の J3 を表面へ移し、基板とカップを +y へ伸ばして片面実装にする (#32)
    * fix(pcb): vein_base v0.11 の J3 を表面の Atom の外へ移し、片面 (Economic PCBA) で全部品を付けられるようにする
    J3 (PicoBlade 53261-0471、高さ 3.4) はヘッダー樹脂のすき間 2.54 に入らないので、基板を +y
    (USB-C / PORT.A の反対) へ伸ばし (20.0 x 29.9、y -10.6..+19.3)、J3 を F 面の (0, +16.2) に
    開口 +y で置く。courtyard は y +12.5..+19.3 で Atom の投影 (±12) の外。配線は G5/G6 を B.Cu、
    3V3/GND を F.Cu。CPL は全部品 Top、補正表は station と同じ (0,0,-0.95) のまま。
    Refs ippoan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
    [jlc_bom.csv]
2026-09-25 fix(case): vein_base v0.12 の J3 の溝を courtyard + 0.25 に広げ、viewer の J3 を courtyard の箱にする (#33)
    v0.11 は溝が x ±4.75 で、J3 の courtyard (x ±5.98, y +12.5..+19.3) がスリーブの +y 壁に
    x 4.75..5.98 / y 12.5..13.65 / z 0..0.9 で食い込んでいた (左右計 2.543 mm³)。viewer の J3 は
    x ±4.3 の手書きの箱だったので干渉チェックをすり抜けていた。KiCad 公式の Molex モデル
    (x ±5.08, y +13.6..+18.8) はカップと 0.70 離れていて実物は当たらないが、プレビューでは
    J3 が壁に入って見えた。溝を ±6.23 にし、viewer の J3 を courtyard そのものの箱にして、
    実物より大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
2026-09-25 fix(case): vein_base v0.13 のカップからスリーブをなくし、基板の下と周りだけを囲む (#34)
    M5 の Atomic 系ベースと同じく、VoiceS3R は Ext.Pin に刺して上に載せるだけにする。
    Atom の下端を囲むスリーブと PORT.A の切り欠きをやめ、壁は VoiceS3R の底面の 0.25 下
    (z=-0.25) で止める。外形は空洞 + 壁 1.4 だけで 24.4 x 33.1 x 9.25 (旧 27.3 x 34.55 x 12.5)。
    M2 の共締めと J3 の上開きの溝 (x ±6.23) は残す。基板は変えない。
    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
2026-09-25 docs(station): モジュール寸法の表記を公式値と出典に直す (形状は変えない) (#36)
    VoiceS3R・Unit NFC の外形は M5Stack 公式 STL、指静脈は Waveshare 製品ページの公式寸法と
    一致していたので、「仮の箱」「写真から実測」の表記を公式値 + 出典に直す。細部 (上面ボタン・
    NFC 裏のネジ頭) とケーブルは実測のまま、指静脈はコネクタ位置だけ未確定と明記。
    Z_ATOM_BOT のコメントの計算値を -17.8 に修正。数値・REV・VERSION は変更なし。
    Refs ippoan/vein-base#17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
2026-09-26 fix(site): 相互リンクの nav がグリッドの 1 マスに入って 3D の表示欄が細くなっていたのを直す (#53)
    .wrap は 2 列のグリッドで、#52 で足した nav が 1 マス目を取り、3D の欄が右の 290px 列に
    押し出されていた。nav を header と同じく grid-column: 1/-1 にする。リンク名から箱の型番を外す。
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2026-09-26 feat(pcb): 指静脈 Unit の基板 u1 (SIC5-9-2B 用) と 3D vu10 (#61)
    pcb/vein_unit_board/build_board.py が 78 × 39 (R9.4) の基板を作る: Grove (HY2.0-4P 横向き、
    JST PH S4B-PH-SM4-TB のフットプリント) → XC6206P332MR 3.3 V → J1 (MX1.25 4P 横向き、
    53261-0471 の金具パッドを 9.4 幅に詰めたフットプリントを pcb/vein_base.pretty に追加)。
    RXD / TXD は J1 の横で B.Cu に下ろして指静脈の下を通す。GND は両面ベタ。M2 × 4 はケースのボス
    (66 × 25)。配線はスクリプトに直書き。CI で gerber / drill / pos / CPL / BOM / 原寸 PDF / DRC
    (fab/vein_unit/)。KiCad 7.0.11 (Docker) で DRC 0 / 未接続 0 を確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
    [jlc_bom.csv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]
2026-09-26 fix(pcb): 指静脈 Unit 基板 u2 — Grove を 0.6 内側へ、1µF を Basic 部品に (#62)
    JLC の実装プレビューで HY2.0 (C722729) の本体がフットプリントより 0.7 前に出て、基板の端から
    1.4 はみ出し、ケースの内壁に 0.1 当たっていた。J2 を 0.6 内側へ寄せ、本体の先を基板の端から 0.6
    内側にする (3D vu11 も合わせる)。C1 / C2 を Extended の C14664 から Basic の C15849 (1uF 50V X5R)
    に替え、Extended の追加料金を 1 種類分減らす。
    [jlc_bom.csv]
2026-09-26 fix(pcb): 指静脈 Unit 基板 u3 — Grove をさらに 1.0 内側へ (JLC の部品モデルの実測に合わせる) (#63)
    u2 の見積もり画面で測り直すと、JLC の HY2.0 (C722729) の本体はフットプリントより 0.7 ではなく
    2.1 前に出ていて、u2 でも基板の端から 0.8 はみ出していた (#62 の説明「0.6 内側」は誤り)。
    J2 をさらに 1.0 内側へ寄せ、本体の先を基板の端から 0.2 内側 (ケースの内壁から 0.8) にする。
    コメントの数値を実測値に直し、3D (vu12) も合わせる。
    [build_board.py]
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2026-09-28 feat(station): VoiceS3R の回路を基板に載せた ESP 基板 e1 と、タカチ SW-85B に収める小型の別案 sw1 (#67)
    * feat(pcb): station ESP 基板 e1 — VoiceS3R の回路 (ESP32-S3-WROOM-1 + ES8311 + マイク + NS4150B + スピーカー) を PF 基板に直接載せる
    - pcb/station_esp_board/build_board.py: PF13-4-9 用 station 基板 (92 × 71、穴・DB9・MAX3232・DIP・J3 は同じ位置) に
    M5Stack 公開回路図と同じ GPIO で ESP32-S3-WROOM-1-N8R8 / USB-C / AMS1117 / ES8311 / LMA3729T381 / NS4150B /
    GSPK1304S を配置。Grove は J6 = Unit NFC (G2/G1)、J7 = 予備 (G38/G39)。IR LED なし
    - freerouting 2.4.1 の配線を station_esp_board.ses に保存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
    [jlc_bom.csv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]
2026-09-28 feat(station): SW75 案 sw75a — NFC を外に出し、タカチ SW-75B (50×30×75) に ESP 基板 sw75 と指静脈・DB9 を収める最小案 (#68)
    - pcb/station_esp_board/build_board.py に `sw75` 外形 (40.8 × 68.1) を追加。回路は同じで、片面実装に収めるため
    0402 / SOT-89 LDO / SKRPACE010 ボタン / DIP → 0R リンク + はんだジャンパー / 5-5 mil。DB9・USB-C は +x の側面、
    Grove 2 口は +y の端面、WROOM のアンテナは -x の壁。配線は station_esp_board_sw75.ses、BOM は jlc_bom_sw75.csv
    - ES8311 の GND 引き込み線を 0.127 に (JLC の最小線幅)。3 外形とも DRC OK
    - station/build_station_sw75.py: SW-75B の簡略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
    [jlc_bom_sw75.csv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]
2026-09-28 fix(station): SW75 sw75b — 指静脈ケーブルを C 字 1 回で J3 へ (J3 をソケットの真下・同じ -y 向きに) (#69)
    - 基板 sw75: J3 を指静脈のソケットの真下 (-8.35, -22.5) に移し、口を -y (ソケットと同じ向き) に。
    これまでは口が +y でケーブルが S 字に折り返していた。空いた左下に合わせて MAX3232 を右下へ (回さない)、
    チャージポンプのコンデンサをその左、EN / 3V3 のコンデンサを WROOM の 1..3 番ピンの下へ縦に並べ、
    指静脈スペーサー H1 / H2 を動かす。再配線して DRC OK
    - 筐体 sw75b: 指静脈を +3 (端面まで 8、ケーブルの C 字の分)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
    [build_board.py]
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2026-09-28 feat(station): SW75 sw75e — BOOT ボタンを +x の縁の横押しスイッチにし、側面のピン穴から押せるようにする (#72)
    - 基板 sw75: SW3 (BOOT) を SKRPACE010 (指静脈の下) から横押しの Panasonic EVQP7C01P (C388883) に替え、
    +x の縁の DB9 と USB-C の間 (18.6, 18.8) に置く。押し子は縁から 0.3 出る。場所を空けるため J5 を +y へ 1.0
    - 配線: sw75c の配線を残し、動いた J5 / SW3 まわりのネット (5V, CC1/CC2, UDP/UDN, G0, J5 付近の GND) だけ
    freerouting 2.4.1 で引き直して 1 つの .ses にまとめた (全部引き直すと G4 が 1 本残った)。DRC OK (手元の kicad 7.0)
    - 筐体: +x 側面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
    [jlc_bom_sw75.csv]
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2026-09-28 feat(station): SW130 sw130a — タカチ SW-130B (40×25×130) に DB9・指静脈・VoiceS3R を一列に全部入れる細い案 (#74)
    - 基板: station 基板に sw130 外形を追加 (build_board.py sw130, 34.8 × 122.7, 片面)。回路は station 基板と同じで、
    NFC 用の Grove J6 (G38 = SDA / G39 = SCL, 4.7k プルアップ R1 / R2) だけ足した (BOM は jlc_bom_sw130.csv)。
    J6 は JLC の HY2.0 の本体が長い分、縁から 2.3 内側。freerouting 2.4.1 で未配線 0、DRC OK (kicad 7.0、4 外形とも)
    - 筐体 (station/build_station_sw130.py): タカチの外形図からの簡略形状 (カバーの縁を含む)。VoiceS3R は中央で基板に立ち
    カバ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
    [jlc_bom_sw130.csv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]
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2026-09-28 fix(station): SW130 sw130c — NFC 面の加工図の注記の R を GROVE_CUT から取る (R0.8 の書き残し) (#76)
    #75 で穴を R0.5 にしたが、-x 側面の加工図の注記に R0.8 が直書きで残っていた。
    寸法の欄は 12.6 x 6.7, 4-R0.5 で正しい。注記を GROVE_CUT から作るようにする。
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2026-09-29 fix(station): SW130 sw130g — 固定部材をマルツの品番で決め、床の VHB の厚みを高さに入れる (#82)
    * fix(station): SW130 sw130g — 固定部材をマルツの品番で決め、床の VHB の厚み (1.14) を高さに入れる
    - 床: ASB-303E (M3 × 3 メスメス) を VHB 5952 (1.14) で貼る。基板の上面は 4.6 → 5.7
    - H1..H4: 座金 WN-5 (1.0) + BSB-305E (M3 × 5 オスメス) のオスを基板に通して床のスペーサーへ。
    オス 6 の先端が床に届かないことを assert で見る
    - H5..H7: M3 × 4 バインドねじ (頭 r3 × 2 で干渉チェック)
    - カバーの縁を DB9 の上だけ削る量を DB9 の高さから計算 (0.8 →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
2026-09-29 fix(station): SW130 — USB の上の削りをカバーの縁の内側 (スカート) まで広げる (#82 の干渉 0.6 mm3) (#83)
    #82 で VoiceS3R が 1.1 上がり、USB-C の金属部 (z 17.24) がカバーの +y 端のスカート (y 61.4〜61.7) に当たっていた。
    #82 は build が失敗したまま自動マージされたので、main の干渉チェックを戻す。
2026-09-29 fix(station): SW130 sw130h — J6 を純正 JST S4B-PH-SM4-TB (C265102) に替える (#84)
    JLC から PCBA 注文 SMT026092864643 で「J6 (HY2.0 C722729) のピンがパッドに合わず、
    はんだ面積が小さい」と指摘があり、部品の差し替え (A) を選んだ。フットプリントどおりの
    JST S4B-PH-SM4-TB(LF)(SN) (C265102、Extended、在庫あり) にする。
    - jlc_bom_sw130.csv の J6 を C265102 に
    - build_station_sw130.py: 本体の前端を縁の 0.6 外から 2.3 内に (フットプリントの前端)。
    側面の穴は HY2.0 の本体用の 12.6 × 6.7 のまま (基板は発注済み)
    - build_board.py の docstring と CLAUDE.md を合わせる
    Co-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
    [jlc_bom_sw130.csv]
2026-10-01 fix(pcb): vein_base v0.16 — J1/J2 のピンを差し込み側 4 mm に短くする (#85)
    * fix(pcb): vein_base v0.16 — J1/J2 を差し込み側 4 mm のピンヘッダーに替える (VoiceS3R の 1〜2 mm 浮き対策)
    - BOM: J1 C5156614 → C42419912 (XFCN PZ254V-11-05P-A40)、J2 C5116483 → C42419911 (PZ254V-11-04P-A40)。mating 6 → 4 mm、tail 3 mm、樹脂 2.5 mm
    - viewer のピン上端 6.0 → 4.0、README に注記、VERSION 0.15 → 0.16
    * docs(readme): J1/J2 のピン変更 (v0.16) を atomic 版の節に書く
    * fix(station): station 基板の BOM も J1/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
    [jlc_bom.csv, jlc_bom_sw130.csv]
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2026-10-01 fix(pcb): station 基板 r12b — SW1 のシルクを 2 行に分け、基板の外に切れていた「SW1 1+2」を入れる (#87)
    届いた r10 で「PASS(FC-1200) / 3+4 CROSS」しか読めなかった (33 文字の中央揃え 1 行が −x 端から 6 mm はみ出し、
    残りに SW1 のリファレンスが重なる)。60 × 35 / PF は左揃え 2 行 + SW1 のリファレンスを非表示、SW75 も +x 端から
    はみ出す計算だったので 2 行にする。配線・部品は変えない。SW130 は発注済みなのでそのまま。
    [build_board.py]
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2026-10-05 feat(station): SW130 sw130k / 基板 v0.17 — Grove (J6) をリセットと同じ +x 側面へ移し、加工を 5 面から 4 面に減らす (#89)
    - J6 (NFC の Grove) を -x 側面の DB9 の近く (-10.65, -45) から、+x 側面の指静脈の下 (10.65, -10) へ移した。R1 / R2 も一緒に移した。freerouting 2.4.1 で配線し直した (未配線 0、DRC OK)。裏シルクは r12c
    - ケースの Grove 穴は +x 側面へ移した。角は R0.5 から R1 にした (R0.5 は加工代が上がるため)。-x 側面は加工なし
    - 加工位置図・加工図・型紙を 4 面 (カバー・+x 側面・両端面) に直した
    - 最初の 4 台 (sw130j / 基板 v0.15) は承認図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
    [jlc_bom_sw130.csv]
2026-10-05 feat(station): SW130 sw130l / 基板 v0.18 — J6 を VoiceS3R の手前へ寄せ、+x 側面の Grove 穴とリセットの切り欠きを 1 つにまとめる (#90)
    - J6 を (10.65, -10) から (10.65, 30.8) へ移した。R1 / R2 は (4.0, 29.0) / (4.0, 32.6)。freerouting 2.4.1 で配線し直した (未配線 0、DRC OK)。裏シルクは r12d
    - +x 側面の加工を SIDE_CUT 1 つにした。幅 23.7、底面から 7.9 より上をボディの上縁まで切り欠く。底の角は R1
    - 加工位置図の ② と、+x 側面の加工図・型紙を、切り欠き 1 つに直した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
    [jlc_bom_sw130.csv]
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2026-10-05 fix(station): 3D 印刷の試作 A / B — 3D が出ないのを直し、ふたを M2 皿ねじで留める、Pages のナビに A / B を足す (#92)
    - 3D ページのひな形は、部品のキー shell (ふた) と lid (本体) を前提にしている。本体のキーを tray にしていたので、3D が表示されなかった。キー名を合わせた
    - ふたは、上から M2 x 5 の皿タッピングねじで、本体の壁の内側の受け (3.9 x 6 x 高さ 4.5) に締める。受けの場所は ledges() が、部品・壁の穴・ふたの窓を避けて四隅の近くから選ぶ。3 本未満なら失敗する
    - 天板を 1.8 から 2.2 にした (皿穴の下に 1.25 残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
2026-10-05 fix(station): 3D 印刷の試作 A — ケーブルの余りを 0.3 下げ、DB9 側の左角にもふたのねじを入れる (4 本) (#93)
    ケーブルの余り (簡略形状) の上端 12.6 が、ねじの受けの下端 12.7 に 0.15 の余裕の判定で掛かっていた。そのため、A の DB9 側の左角に受けを置けていなかった。余りを 0.3 下げ、A のねじは四隅の 4 本になった。干渉なし。肉厚 1.0 OK。
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2026-10-05 fix(pcb): JLC の CPL で J6 (JST S4B-PH-SM4-TB) が 180 度逆に載るのを直す — 回転の補正を 0 から 180 にする (#96)
    JLCPCB の実装プレビュー (Component Placements) で、print_a の J6 の部品モデルが逆向きに出た。モデルのピンが基板の縁の側にあり、パッドは内側にあった。補正を 180 にした CPL を入れ直すと、ピンがパッドに乗り、口が基板の縁を向いた。オフセット (0, 1.05) はそのまま。
    この補正表は sw130 にも効く。発注済みの sw130 v0.15 (J6 が -x) も、同じ補正 0 で CPL を出していた。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
    [jlc_cpl_corrections.csv]
2026-10-06 feat(station): 3D 印刷の試作 B — 指静脈を基板に VHB で貼りふたの枠で押さえる、DB9 をふたの上に出して高さ 16.7 (#97)
    * fix(station): 3D 印刷の試作 B — 指静脈を基板に VHB でじかに貼り、ふたの枠で横を押さえる
    B の指静脈を載せる枠は基板の上に置いてあるだけで、本体にもふたにもつながっていなかった
    (「箱と一体」の説明と違い、接着剤でしか留められない形だった)。
    - 指静脈は基板に VHB (1.1) でじかに貼る。上面はふたとほぼ面一 (+0.3)
    - 横はふたから下ろした枠 (天板の裏から 5、厚さ 1.6、+x と +y の 2 辺) で押さえ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
2026-10-06 fix(station): 3D 印刷の試作 B — ふたの細い部分をなくし (L 字)、指静脈の横は本体の壁で、下は床のリブで受ける (#102)
    ふたの指静脈のまわり (−x と手前、幅 2.3) と、指静脈と VoiceS3R の間 (幅 2.5) が細く、折れそうだった
    (ユーザー指摘)。
    - ふたは指静脈のまわりと手前 (VoiceS3R の前まで) を切った L 字にした
    - −x と手前は本体の壁を天板の高さまで上げ、指静脈の横を押さえる
    - +x と奥はふたの縁から下ろした枠 (深さ 5) で押さえる
    - 床のリブを基板の下面 (2.0) まで上げ、指で押す力を面で受ける。真ん中の台はやめた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
2026-10-07 fix(station): 指静脈 Unit vu14 — SIC5-9-2 の型紙の外形を実物 (両端 R34 + 角 R12) に直す (#106)
    型紙の蓋の外形を R12.5 の角丸長方形で描いていたが、実物を当てると角が合わなかった
    (2026-10-07)。タカチの SIC5-9-2W.dxf では、上から見た外形は長い辺が直線 (60.7)、
    両端が R34 の弧 (中心は軸上、先端から 34 内側)、その間を R12 の角でつないだ形。
    - station/template.py: 両端が弧のケースの外形 arc_ends_xy() と、端の弧と角の境目
    arc_ends_tangent() を足し、view() の outline に点列も渡せるようにする
    - build_vein_unit.py sic: 型紙の外形を (R34, R12) に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
2026-10-07 fix(station): 指静脈 Unit vu15 — 端面の型紙の上端を外から見える合わせ目 (底から 16) にする (#107)
    型紙の端面の図は本体の内側の縁 (底から 17.5) までで描いていて、穴の上端を
    「縁から 3.7 下」と書いていた。外から見えるのは本体と蓋の合わせ目のでっぱり
    (タカチの図面で本体 16 + 蓋 4) なので、側面とでっぱりの関係が分からなかった。
    - sic の END の高さを SEAM = 16.0 にし、穴の上端は「合わせ目から 2.2 下」と書く
    - 穴は底 (机の面) から測るという一文を注記に足す
    - 穴の位置 (底から 7.2〜13.8、幅 9.2、中央) は変わ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
2026-10-07 feat(station): Vein Unit P (vp1) — 3D 印刷・段差受けの指静脈 Unit と基板 u4 (#110)
    * refactor(station): 3D 印刷の箱の共通関数 (shell_and_lid / ledges / rib_grid / check) を shapes.py へ移し、z_in を引数にする。指静脈の実測形 (段と溝) を足す
    build_station_print.py の A / B は出力 (STL・ページ) がバイト単位で同じ。
    Refs ippoan/vein-base#109
    * feat(station): Vein Unit P — 指静脈モジュールだけを入れる 3D 印刷の箱 (vp1) と基板 u4 (build_board.py p)
    - station/build_vein_unit_print.py (REV vp1, site/vein-unit-print/): shapes.shell_and_lid の箱。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
    [jlc_bom_p.csv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]
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2026-10-07 fix(station): Vein Unit P vp3 — 基板 u4 の四隅をふたの受けの分切り欠き、上から落とし込めるようにする (#114)
    - 基板は部品ごと上から入れるので、受け (壁の内側 3.9、ふたから 4.5 下) を xy で避ける。受け + 0.3、縁まで 2.0 未満なら縁まで (NOTCHES、ケースと基板の 2 か所)
    - build_vein_unit_print.py: 受けの位置 (shapes.ledge_rect) から切り欠きを確かめ、基板・J1・J2・LDO・指静脈・9P プラグが受けに当たらないことを assert
    - U1 / C1 / C2 は +x/+y の切り欠きの外へ (J2 の +y 側に縦一列)、5V / 3V3 の配線とビアを直す (pcbnew のモックで間隔 0.2・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
    [build_board.py]
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2026-10-08 feat(station): 3D 印刷 B の J3 を縦型にして 9P の手前に置き、ロックが同じ面の自作ケーブルに合わせる (#125)
    * feat(station): 3D 印刷 B — J3 を縦型 53398 にして指静脈の 9P プラグの手前に立て、自作ケーブル(両端のロックが同じ面)に合わせる
    ユーザー決定 (2026-10-08): 9P → 4P ケーブルは自作で両端のロックを同じ面にしてまっすぐ並べる。
    横型 J3 を指静脈の下に置く形では、ケーブルの U ターンで面が裏返るので入らない。
    - print_b: J3 を Molex 53398-0471 (縦型、C17617036) に替え、(-14.5, -41.8) に 180° で
    (MP と本体が 9P プラグから 0.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
    [jlc_bom_print_b.csv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]
2026-10-08 fix(station): SW1 の 3D の高さを実物の 4.05 にし、3D 印刷 B の指静脈の台を 3.9 → 4.4 に上げる (#126)
    * fix(station): SW1 の高さを実物の 4.05 に合わせ、B の指静脈の台を 4.4 にする (Refs #109)
    CTS 219-4LPSTRF は本体 3.80 + スタンドオフ 0.25 で基板から約 4.05。3.0 で描いていたため
    B の台 3.9 では指静脈の下面に 0.15 当たった。VERSION 0.36。
    * fix(station): A のケーブルの余りの置き場の下端を SW1 の上 + 0.3 に上げる (Refs #109)
    SW1 を 4.05 にしたので、下端 ZBT + 3.7 では干渉した。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
2026-10-08 fix(station): Vein Unit P vp5 — ふたの受けを 4 つとも ±x の壁にそろえる (#128)
    * feat(station): Unit P のふたの受けを 4 つとも ±x の壁にそろえる
    ledges() / shell_and_lid() に walls 引数(既定は 4 面)を足し、Unit P は ('x-', 'x+') を渡す。
    NOTCHES を (-37.3, -33.4, 7.6, 15.0) に更新し、基板の GND ビアを切り欠きの外へ。
    A / B の STL は変わらない。VERSION 0.37。
    * chore(station): Unit P の REV を vp5 に上げる(ふたの受けと NOTCHES が動いたため)
    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
    [build_board.py]
2026-10-08 feat(station): 3D 印刷 B を低く作り直す — 指静脈を基板に直接、下の部品を VoiceS3R の下へ (57.9 × 74.6、フード 20.1) (#129)
    * refactor(station): 指静脈の窓・座ぐりとケーブルの両側面の置き場を shapes.py へ移す
    Unit P の出力 (STL) はバイト一致。3D 印刷 B でも使う。
    * refactor(station): 指静脈のケーブルの置き場 (9P プラグ・両側面・溝・4P の上) を shapes.vein_cable に
    Unit P の STL はバイト一致。
    * feat(station): 3D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
    [jlc_bom_print_b.csv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]
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2026-10-17 fix(station): Grove ソケットを JST PH から HY2.0 (C722729) に戻す — Unit P の J2 と 3D 印刷 B の J6 (v0.39, vp6) (#131)
    届いた Unit P 基板 v0.38 の J2 (JST PH S4B-PH-SM4-TB, C265102) に Grove のケーブルが挿さらなかった
    (2026-10-17 実物)。#84 で JLC に「HY2.0 のピンがパッドに合わない」と言われたとき、直すべきは
    KiCad の PH のフットプリントのパッドだった。
    - pcb/vein_base.pretty に C722729 の実寸のフットプリント (LCSC / EasyEDA の CONN-SMD_HY2.0-4P を
    easyeda2kicad で取得、MP を MP に改名、シルクの耳の段を除く)。原点と向きが EasyEDA と同じなので
    CPL の補正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
2026-10-17 fix(station): 3D 印刷 B の DB9 と J6 を奥へ 3.4 — 実物のシリアルプラグ (幅 34.2) と VoiceS3R の間を 2.0 空ける (v0.40, 57.9 × 78.0) (#132)
    * fix(station): 3D 印刷 B の DB9 と J6 を奥へ 3.4 — シリアルケーブルのプラグと VoiceS3R の間を 2.0 (v0.40)
    v0.38 の実物で DB9 に挿したプラグ(実測 最大幅 34.2、厚み 14.6)の側面が VoiceS3R に
    当たった。干渉チェックのプラグは幅 30.3 ですき間 0.55 だった。
    - shapes.db9() のプラグの半幅 15.15 → DB9_PLUG_W = 17.1(実測)
    - concept_b: DY = ay + 12 + DB9_GAP_B (2.0) + DB9_PLUG_W、右の列の奥の縁だけ yo1r
    (フードの奥の面 yo1 は据え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
2026-10-17 fix(station): 足の逃げを実測に合わせる — J1 / J2 の穴を消し、B の DB9 の固定の足の下に ⌀5 の穴 (v0.43) (#135)
    * fix(station): 3D 印刷 B / C の足の逃げを実測に直す — J1 / J2 の穴を消し (足 1.5)、B の DB9 の足 (2.5) の真下の床に穴 (v0.43)
    2026-10-18 に v0.38 の B の実物で測った: J1 / J2 の足は基板の下へ 1.5 で床に当たらず、
    DB9 の両端の固定の足は 2.5 で床に 0.5 食い込む。
    - tail_slots() / TAIL_SLOT_* / 床の J1 / J2 の穴を B・C から外し、足を 1.5 (TAIL_HDR) で干渉チェック、床の上面とのすき間 0.5 を assert
    - B: db9_tail_holes() で DB9 の足 (固定 2 本 +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
2026-10-17 fix(station): rib_grid で全部切れた棒が後の避け箱で戻る不具合を直す — c26 の DB9 切り直しを外す (v0.44) (#136)
    先の避け箱で空になった棒に後の cut をかけると CadQuery が元の棒を返していた。空になったら捨てる。
    B の本体は main と同じ形(差 0.02 mm3)、A / C / Unit P の STL は同一。干渉なし、肉厚 1.0。
    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
2026-10-17 fix(station): 3D 印刷 B の DB9 の口の筒の先端を基板の縁に — 挿したプラグは筒の先端から、すき間 0.3 に戻す (v0.45, 57.9 × 74.6) (#137)
    - shapes.db9(): プラグの始まりを枠の 0.8 先から口の筒の先端 (DB9_SHELL_L = 6.0) に (2026-10-18 のユーザーの写真)。
    print_a は plug_from=0.8 で従来のまま (筒の先端からだと A のふたの縁が作れない)。A の STL は不変
    - concept_b(): bx1 = xo1 − DB9_SHELL_L、DY は DB9 の枠と VoiceS3R の 0.3 から。筒の下の基板と床を ±9.0 で切り抜く。
    プラグのすき間の assert は「プラグは基板の +x の縁より外」に
    - build_board.py print_b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
2026-10-17 fix(station): 3D 印刷 B の DB9 のピン 1 の列から枠の前面を 10.94 に — 名前の 7.70 は基板の縁まで (v0.47) (#140)
    KiCad の DSUB-9_Male_Horizontal_P2.77x2.84mm_EdgePinOffset7.70mm_... の F.Fab では、
    ピン 1 の列から枠の前面まで 10.94 (本体 −1.8〜10.54、枠 10.54〜10.94、筒 10.94〜16.94)。
    名前の 7.70 はピン列から基板の縁までで、v0.38〜v0.46 はこれを枠の前面と取り違え、
    B の DB9 は図より 3.24 外へ出ていた。
    - shapes.py: DB9_PIN_FACE = 10.94、db9() の本体・枠を F.Fab に (枠の後ろ 12.74、枠 0.4、
    ±15.425)。旧形は DB9_LEGACY (print_a はこれを使い、形は変わらない)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
2026-10-21 fix(station): 3D 印刷 B / C のフードを 0.5 上げる — 届いた B で指静脈を載せるとフードが床から 0.5 浮いた (v0.49) (#142)
    リブ 2.0 + 基板 1.6 + 指静脈の胴 13.0 の積み上げに余裕 0 で作っていた。
    フードの天板の裏と座ぐりを HOOD_UP_B = 0.5 上げる(−x の柱は床から伸び、
    +x の柱は基板の上なので、M2 × 12 のねじの長さとかかりは変わらない)。
    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
2026-10-21 fix(station): 3D 印刷 B の床と基板のナットを右の列 4 → 2 に (v0.53) (#146)
    右の列のナット 4 つは無駄に多い(2026-10-21 ユーザー)。(3.1, −11.0) と
    (21.8, −30.3) をやめ、床 → 基板は右の列の 2 本(DB9 の後ろの奥寄り、J6 の横)と
    フードの手前・奥の真ん中の 2 本(六角の逃げ)の計 4 本に。配線はそのまま(DRC OK)。
    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
2026-10-29 fix(pcb): HY2.0 の Grove の並びを線の色に合わせる — print_b の J6 と Unit P の J2 (v0.58) (#152)
    HY2.0 (C722729) の 1 番パッドには Grove ケーブルの黒 (GND) が来る。v0.57 までは 1 番を信号にしていたため、
    M5 のストレートのケーブルで Unit NFC の GND が G38 に、SDA が 5V に入っていた (2026-10-29 実機。
    逆順のケーブルにすると SDA=G39 / SCL=G38 で応答し、免許証まで読めた)。
    - print_b の J6: 1:GND 2:5V 3:G38 (SDA、黄) 4:G39 (SCL、白)。freerouting 2.4.1 で引き直した
    (未配線 0)。裏のシルクを NFC: G 5V G38 G39 に、BOM の注記も直した
    - Unit P (u4) の J2: 1:GND 2:5V 3: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
2026-10-29 fix(station): 3D 印刷 B の Unit NFC を DB9 から 3.0 離す — 棚の上に台 (v0.59) (#153)
    v0.58 までは Unit NFC が棚の上面 (フードの天板の裏の高さ) に直接載り、裏が DB9 の上面から 0.3 しか
    離れていなかった。実機 (2026-10-29) では、その位置でカードをまったく検知しなかった (振幅は 28/30 で
    ほぼ変わらず、DB9 の殻の渦電流で磁界が打ち消される)。床の板 (2.0) を挟むと読めた。
    - 棚の上に、NFC の足元 (棚にかかる範囲) だけの台を足し、NFC の裏を DB9 の上面から NFC_OFF_DB9 = 3.0 に
    - 柱・ねじの頭・下穴を持ち上げた分だけ上げる (ねじ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
2026-10-29 feat(station): 3D 印刷 B の Unit NFC と DB9 のすき間を台で埋め、奥の角に柱 (v0.60) (#154)
    * feat(station): 3D 印刷 B の Unit NFC と DB9 のすき間も台で埋める (v0.60)
    v0.59 の台は棚にかかる範囲だけで、NFC の後ろ 3/4 (DB9 の上) は 2.7 浮いていた。
    台を NFC の足元全体に広げ、DB9 の上は上面から 0.3 のところから NFC の裏まで埋める (ユーザー指示)。
    NFC の裏は DB9 から 3.0 のまま。干渉チェック: a / b / c とも interference: none (B の体積 20.5 → 22.4 cm3)。
    Refs ippoan/alc-app#514
    * feat(station): 3D 印刷 B の Unit NFC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
2026-10-29 fix(station): 3D 印刷 B の NFC の台とフードの間の 0.3 の溝を埋める (v0.61) (#155)
    台を Unit NFC の外形どおりに作っていたので、NFC がフードから離れる 0.3 がフードの +x の面に沿った
    細い溝として残っていた (ユーザー指摘「無駄な切込み」)。台をフードの +x の面まで延ばして埋める。
    延ばす部分は高さをフードの天板の上面まで、手前はフードの R3 の角の先から、奥は NFC の R2 の角の手前まで
    (その外では幅 0.3 のひれが残り check_thickness.py で 0.32〜0.61 の薄肉になった)。
    干渉チェック a / b / c とも interference: none、check_thickness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
2026-10-29 fix(station): 3D 印刷 B の NFC の台とフードの境目の V 字の切れ込みを無くす (v0.62) (#156)
    v0.61 は薄肉を避けるため、溝の埋めを手前 3 (フードの R3 の角) と奥 2 (NFC の R2 の角) で止めていて、
    手前の角に V 字の切れ込みが残った (ユーザー指摘)。
    - フードと NFC の間 0.3 は、フードの天板の上面まで手前から奥まで埋める (天板より上は横に支えが無く 0.32 のひれになるので止める)
    - NFC の台のフード側の角を四角にして台の上面まで
    - フードの天板の手前 +x の R3 の角を四角に
    lid を真上と手前から測り、境目の上面は 18.6 (フー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
2026-11-11 fix(station): 3D 印刷 B の DB9 を 1.0 外へ出す — プラグが縁・NFC の台・VoiceS3R に当たる (v0.63) (#158)
    * fix(station): 3D 印刷 B の DB9 を 1.0 外へ出し、プラグが縁・NFC の台・VoiceS3R に当たらないように (v0.63)
    実物の B でシリアルケーブルのプラグを強く押し込まないと挿さらなかった。プラグの面(DB9 の筒の先端)が
    基板の縁・NFC の棚の壁と台・VoiceS3R の面とすき間 0 で同じ面だったため。
    - DB9 (J4) を +x へ 1.0(筒の先端が縁の 1.0 外、DB9_OUT_B / DB9_OUT)
    - 枠が H8 のナットに 0.4 載るので H8(床と基板の皿小ねじ + ナット)を無くす(ユーザ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
2026-11-11 fix(pcb): print A / B / C の裏シルクに版を入れる、print B の印字をパッドから外す (v0.64) (#159)
    REV (r12) を上げ忘れていて、print B の基板は何度変えても裏シルクが r12 のままだった。
    VERSION から入れるので上げ忘れない。print B の印字は J1 のパッドとビアにかかって欠けていたので -x へ寄せた。
